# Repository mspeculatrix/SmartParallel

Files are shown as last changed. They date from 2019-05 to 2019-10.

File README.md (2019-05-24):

# SmartParallel

A KiCad-based hardware project to create a 'smart' serial to parallel adapter, initially to allow printing to dot matrix printers. It is designed not just to turn a serial stream into eight-bit parallel but also deal with certain of the other lines used in Centronics interfaces, such as /Strobe etc.

Uses a TTL serial connection to a client machine (such as a Raspberry Pi). This connects to an Atmel ATMEGA328PB microcontroller.

The microcontroller sets up the eight data lines using a 74HC595 shift register. Other Centronics signals, such as /Strobe, are handled via a 74HC541 tri-state buffer.

There are verious LEDs providing blinkenlights - some with their logic inverted via a 74HC14 Schmitt inverter IC.

An ISP header allows programming of the microcontroller.

An I2C header is provided - this is intended for an LCD display (optional).

THIS IS A WORK IN PROGRESS and is far from complete.

See: https://mansfield-devine.com/speculatrix/category/projects/smartparallel/

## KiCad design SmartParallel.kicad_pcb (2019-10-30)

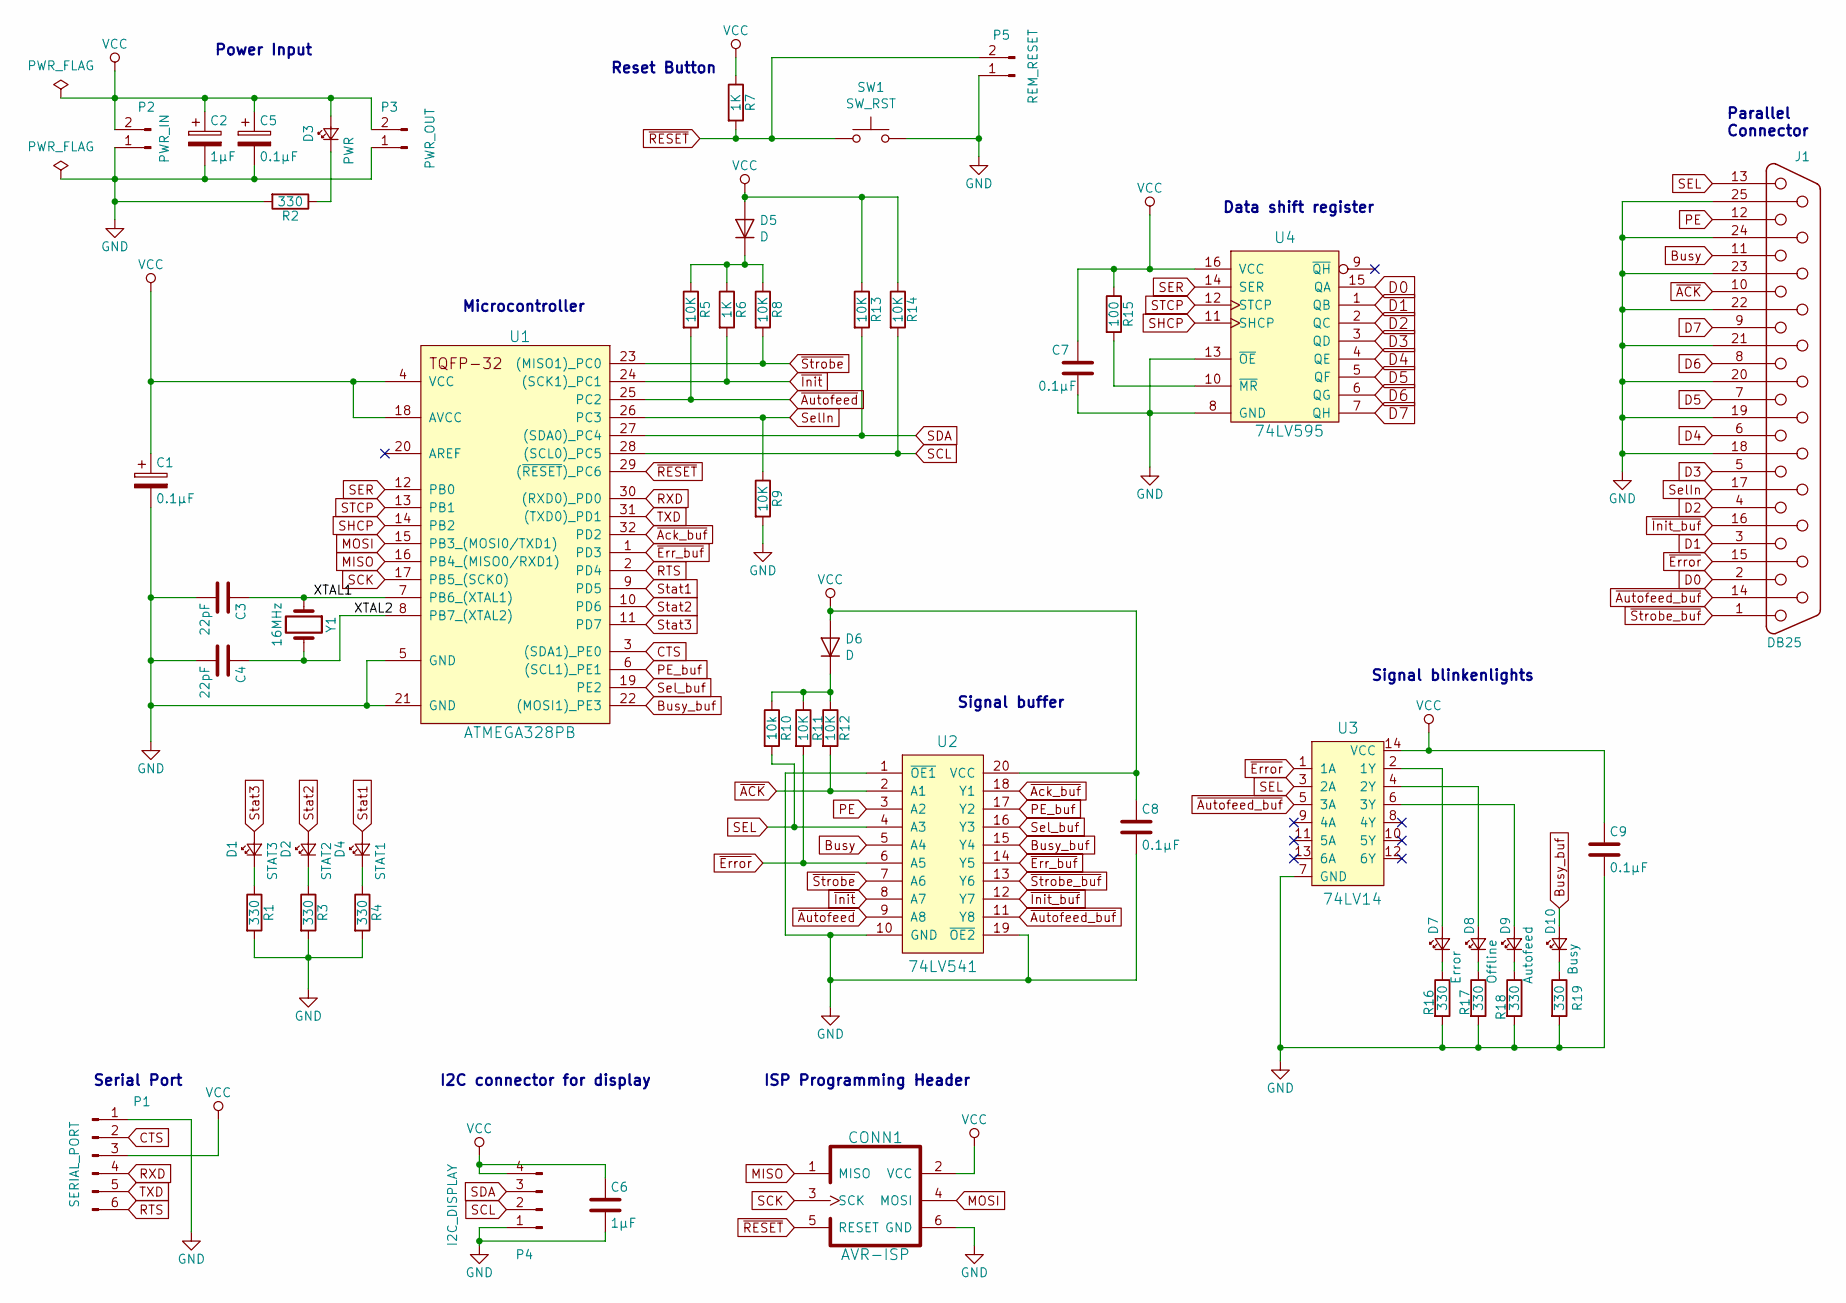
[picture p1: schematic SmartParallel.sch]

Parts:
C1, C5, C7, C8, C9: 0.1µF; C_1206
C2, C6: 1µF; C_1206
C3, C4: 22pF; C_1206
CONN1: AVR-ISP; AVR_ISP_HE10_2x3
D1: STAT3; LED_1206
D2: STAT2; LED_1206
D3: PWR; LED_1206
D4: STAT1; LED_1206
D5, D6: D; Diode_SOD-123F-S-FLAT
D7: Error; LED_1206
D8: Offline; LED_1206
D9: Autofeed; LED_1206
D10: Busy; LED_1206
J1: DB25; DB25FC
P1: SERIAL_PORT; Pin_Header_Angled_1x06
P2: PWR_IN; Pin_Header_Angled_1x02
P3: PWR_OUT; Pin_Header_Straight_1x02
P4: I2C_DISPLAY; Pin_Header_Straight_1x04
P5: REM_RESET; Pin_Header_Straight_1x02
R1, R2, R3, R4, R16, R17, R18, R19: 330; R_1206
R5, R8, R9, R11, R12, R13, R14: 10K; R_1206
R6, R7: 1K; R_1206
R10: 10k; R_1206
R15: 100; R_1206
SW1: SW_RST; SW_PUSH_6mm
U1: ATMEGA328PB; TQFP-32_7x7mm_Pitch0.8mm
U2: 74LV541; SOIC-20W_7.5x12.8mm_Pitch1.27mm
U3: 74LV14; SOIC-14_3.9x8.7mm_Pitch1.27mm
U4: 74LV595; SOIC-16_3.9x9.9mm_Pitch1.27mm
Y1: 16MHz; Crystal_SMD_EuroQuartz_MQ2-2pin_7.0x5.0mm

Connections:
/XTAL1: C3.1, U1.7 (PB6_(XTAL1)), Y1.1
/XTAL2: C4.1, U1.8 (PB7_(XTAL2)), Y1.2
Busy: J1.11, U2.5 (A4)
Busy_buf: D10.2 (A), U1.22 ((MOSI1)_PE3), U2.15 (Y4)
CTS: P1.2, U1.3 ((SDA1)_PE0)
D0: J1.2, U4.15 (QA)
D1: J1.3, U4.1 (QB)
D2: J1.4, U4.2 (QC)
D3: J1.5, U4.3 (QD)
D4: J1.6, U4.4 (QE)
D5: J1.7, U4.5 (QF)
D6: J1.8, U4.6 (QG)
D7: J1.9, U4.7 (QH)
GND: C1.2, C2.2, C3.2, C4.2, C5.2, C6.2, C7.2, C8.2, C9.2, CONN1.6 (GND), J1.18, J1.19, J1.20, J1.21, J1.22, J1.23, J1.24, J1.25, P1.1, P2.1, P3.1, P4.1, P5.1, R1.2, R2.2, R3.2, R4.2, R9.2, R16.2, R17.2, R18.2, R19.2, SW1.2, U1.5 (GND), U1.21 (GND), U2.1 (~OE1), U2.10 (GND), U2.19 (~OE2), U3.7 (GND), U4.8 (GND), U4.13 (~OE)
MISO: CONN1.1 (MISO), U1.16 (PB4_(MISO0/RXD1))
MOSI: CONN1.4 (MOSI), U1.15 (PB3_(MOSI0/TXD1))
unnamed: D1.1 (K), R1.1
unnamed: D2.1 (K), R3.1
unnamed: D3.1 (K), R2.1
unnamed: D4.1 (K), R4.1
unnamed: D5.1 (K), R5.1, R6.1, R8.1
unnamed: D6.1 (K), R10.1, R11.1, R12.1
unnamed: D7.1 (K), R16.1
unnamed: D7.2 (A), U3.2 (1Y)
unnamed: D8.1 (K), R17.1
unnamed: D8.2 (A), U3.4 (2Y)
unnamed: D9.1 (K), R18.1
unnamed: D9.2 (A), U3.6 (3Y)
unnamed: D10.1 (K), R19.1
unnamed: R15.2, U4.10 (~MR)
PE: J1.12, U2.3 (A2)
PE_buf: U1.6 ((SCL1)_PE1), U2.17 (Y2)
RTS: P1.6, U1.2 (PD4)
RXD: P1.4, U1.30 ((RXD0)_PD0)
SCK: CONN1.3 (SCK), U1.17 (PB5_(SCK0))
SCL: P4.2, R14.2, U1.28 ((SCL0)_PC5)
SDA: P4.3, R13.2, U1.27 ((SDA0)_PC4)
SEL: J1.13, R10.2, U2.4 (A3), U3.3 (2A)
SER: U1.12 (PB0), U4.14 (SER)
SHCP: U1.14 (PB2), U4.11 (SHCP)
STCP: U1.13 (PB1), U4.12 (STCP)
SelIn: J1.17, R9.1, U1.26 (PC3)
Sel_buf: U1.19 (PE2), U2.16 (Y3)
Stat1: D4.2 (A), U1.9 (PD5)
Stat2: D2.2 (A), U1.10 (PD6)
Stat3: D1.2 (A), U1.11 (PD7)
TXD: P1.5, U1.31 ((TXD0)_PD1)
VCC: C1.1, C2.1, C5.1, C6.1, C7.1, C8.1, C9.1, CONN1.2 (VCC), D3.2 (A), D5.2 (A), D6.2 (A), P1.3, P2.2, P3.2, P4.4, R7.1, R13.1, R14.1, R15.1, U1.4 (VCC), U1.18 (AVCC), U2.20 (VCC), U3.14 (VCC), U4.16 (VCC)
~ACK: J1.10, R12.2, U2.2 (A1)
~Ack_buf: U1.32 (PD2), U2.18 (Y1)
~Autofeed: R5.2, U1.25 (PC2), U2.9 (A8)
~Autofeed_buf: J1.14, U2.11 (Y8), U3.5 (3A)
~Err_buf: U1.1 (PD3), U2.14 (Y5)
~Error: J1.15, R11.2, U2.6 (A5), U3.1 (1A)
~Init: R6.2, U1.24 ((SCK1)_PC1), U2.8 (A7)
~Init_buf: J1.16, U2.12 (Y7)
~RESET: CONN1.5 (RESET), P5.2, R7.2, SW1.1, U1.29 ((~RESET~)_PC6)
~Strobe: R8.2, U1.23 ((MISO1)_PC0), U2.7 (A6)
~Strobe_buf: J1.1, U2.13 (Y6)

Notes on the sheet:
ISP Programming Header
I2C connector for display
Serial Port
Power Input
Reset Button
Data shift register
Signal buffer
Signal blinkenlights
Microcontroller
Parallel Connector

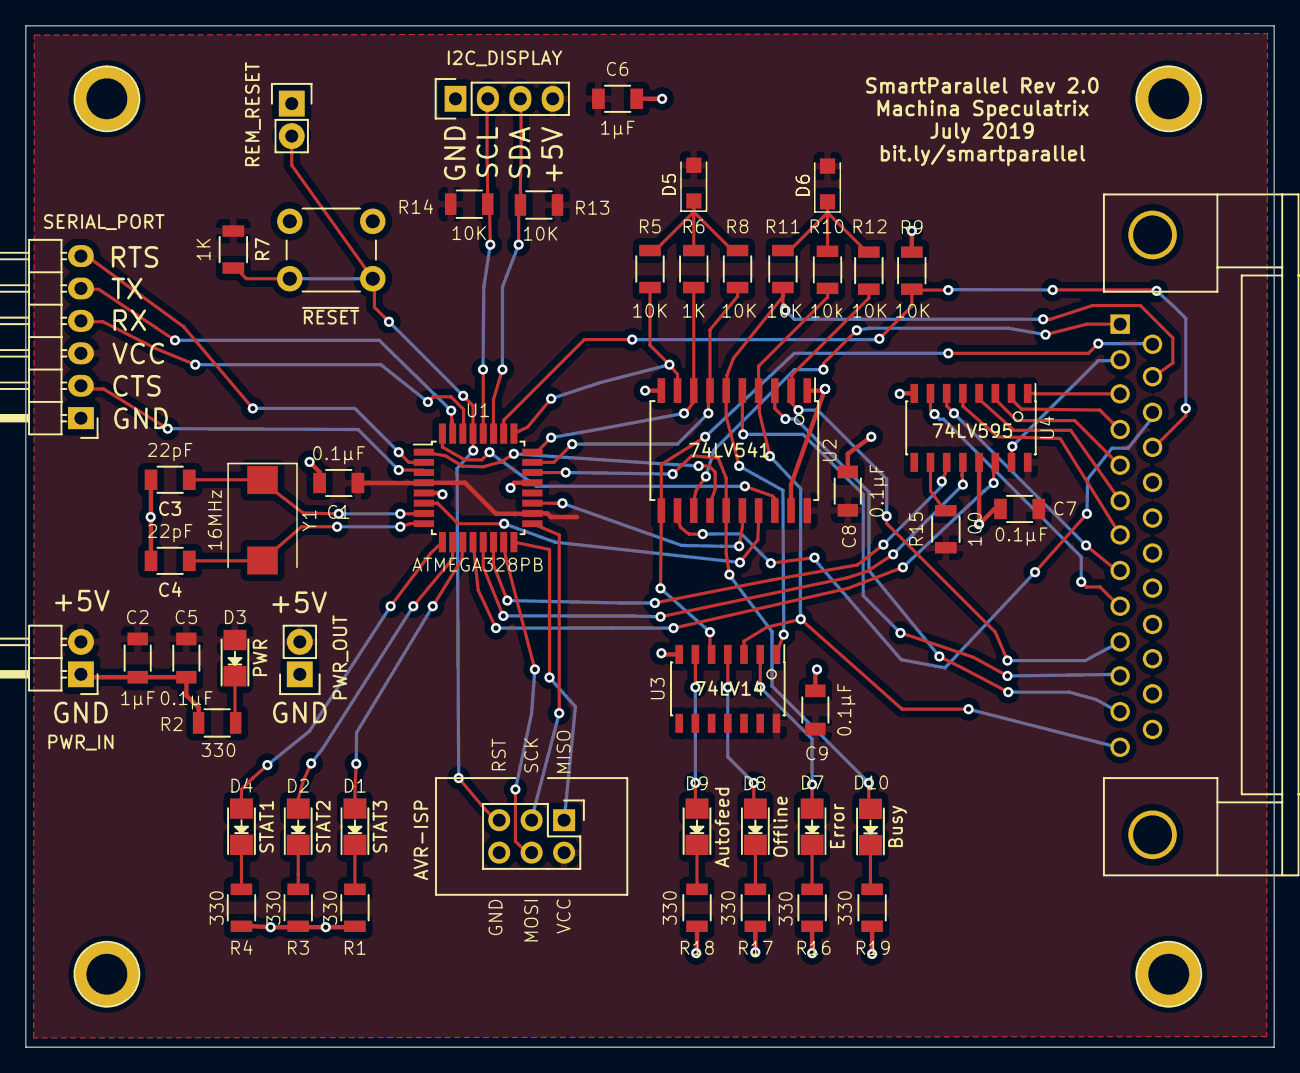
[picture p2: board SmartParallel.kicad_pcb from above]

Board: 2 copper layers, 97.8 x 80.0 mm, 51 parts (0 on the bottom side), 59 nets.

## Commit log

2019-05-24 First upload
    [SmartParallel.kicad_pcb, SmartParallel.sch]
2019-05-24 Fixed library issues
    [SmartParallel.sch]
2019-05-24 Minor updates
    [SmartParallel.kicad_pcb, SmartParallel.sch]
2019-06-06 First completed PCB
    [SmartParallel.kicad_pcb, SmartParallel.sch]
2019-06-06 minor update
    [SmartParallel.sch]
2019-07-05 many small changes
    [SmartParallel.kicad_pcb, SmartParallel.sch]
2019-07-12 Final version of Rev.2.0 schematic
    [SmartParallel.sch]
2019-07-23 Misc tweaks
    [SmartParallel-B_Cu.gbr, SmartParallel-B_Mask.gbr, SmartParallel-B_SilkS.gbr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]
